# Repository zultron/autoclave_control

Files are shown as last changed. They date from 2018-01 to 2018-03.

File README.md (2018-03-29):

# Machinekit Autoclave control

This project is the design for an autoclave control using Machinekit
and a BeagleBone.  It controls a heat element and a pressure relief
valve using thermistors for input.

This repo is a rework of the [Goldibox][goldibox] project repo.

[goldibox]: https://github.com/zultron/goldibox/

## Components

The autoclave controller is a BeagleBone computer running Debian.  It
senses temperatures through a pair of thermistors attachd to its
analog inputs, and it switches the heat element and pressure relief
valve through two solid-state relays (SSRs) connected through GPIO
digital output pins.  See `electronics/autoclave.fzz` for connecting
them.

The [Machinekit][machinekit] software runs the configuration in this
repository:  some python user-space components in the `bin/`
directory, and HAL configuration in the `hal/` directory.  The
`autoclave-control` component decides whether to switch the relief
valve and burner on or off, depending on the program cycle and the
measured temperature.  The `autoclave-logger` component logs to a RRD
database, from which time series charts are generated.

The `autoclave-control` component exposes a remote UI, used by the
`MachinekitClient` software, which can be downloaded for Android from
the Google Play store, and for Linux, Mac OS X and Windows directly
from the [QtQuickVCP][qqvcp] project.  See the below screenshot.  The
idle, boil, steam and heat stages in green are done.  The current
stage is 15+ minutes into a 30 minute sterilization.  That and the
blue-colored cool stage are not yet done.  The button controls on the
left are enable/disable, start/stop, and a link to the graphs.  The
indicators on the upper right are process elapsed time, burner duty
cycle, pressure and temperature.

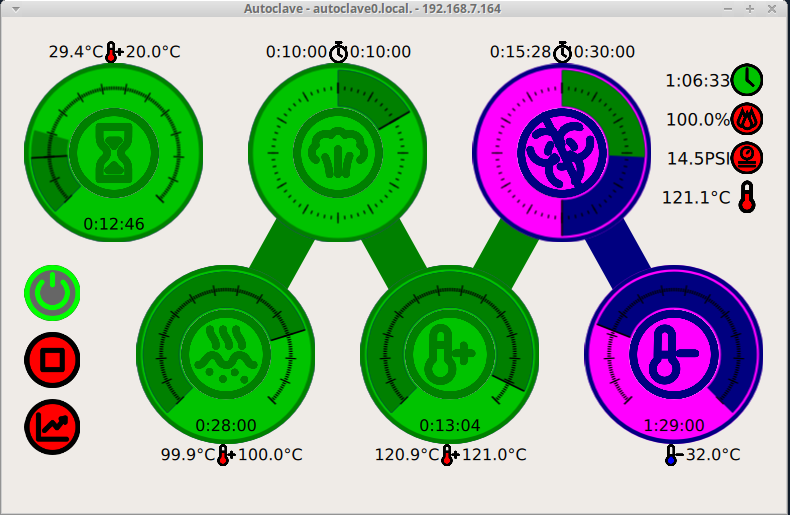
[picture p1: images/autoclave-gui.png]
Autoclave GUI


The `autoclave-logger` component captures process data with
[rrdtool][rrdtool] and generates graphs like the one below, which
shows an entire cycle on a real machine.  The autoclave was already
warmed up to 29.4 deg. from a previous run when the start button was
pressed shortly after 03:00.  The water was heated to 100 degrees in
the boil stage, and the valve was opened (thick blue curve) for ten
minutes with the burner at 100% (yellow curve; 0% at 100, 100% at
110).  Then the valve closed and the autoclave was heated to the 121
degree sterilization temperature.  Pressure was also measured at 15
PSIG (solid orange curve).  After 30 minutes, the burner was turned
off and the autoclave cooled to 32 degrees (not shown), and the cycle
was finished.  After that, the autoclave switch back to idle mode at
20 degrees.

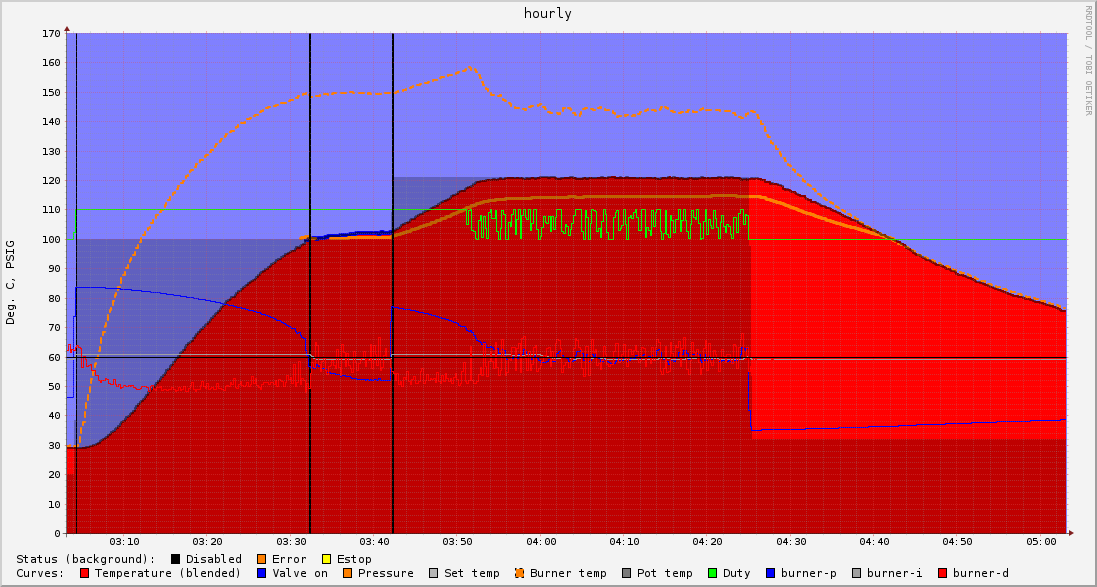
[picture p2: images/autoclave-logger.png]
Autoclave logger


[rrdtool]: https://oss.oetiker.ch/rrdtool/

FIXME:  configuration?

# Running

Follow the instructions at [machinekit.io][machinekit] to download and
install a mini-SD card image with Machinekit.  Log into the BeagleBone.

On the BeagleBone, install the `python-yaml` package.

     sudo apt-get install -y python-yaml

Clone this repository, and `cd` into the repository directory.

     git clone https://github.com/zultron/autoclave_control
     cd autoclave_control

On the BeagleBone, start the Autoclave control from the command line
(load the overlay file for non-system installs):

    # Install minimal apache and other config
    sudo make install MININSTALL=1
    # Start control
    bin/autoclave -o

The Autoclave should now be ready for control.  Start the
[MachinekitClient][qqvcp] and open the Autoclave app.

Alternatively, run an Autoclave simulated control and GUI in a Docker
container from the command line:

    # Start the container
    docker/qqvcp.sh
    # Install minimal apache and other config
    sudo make install MININSTALL=1
    # Start control
    bin/autoclave &
    # Start GUI
    MachinekitClient &

The Autoclave may be installed to the system so that it is run at
every boot:

    sudo make install
    sudo systemctl daemon-reload
    sudo systemctl enable autoclave
    sudo systemctl start autoclave

The `apache2` package must be installed and the web server running for
the time-series chart to work.

# Installing the BeagleBone

FIXME

[wiki-peltier]: https://en.wikipedia.org/wiki/Thermoelectric_cooling
[machinekit]: http://www.machinekit.io/
[qqvcp]: https://github.com/qtquickvcp/QtQuickVcp

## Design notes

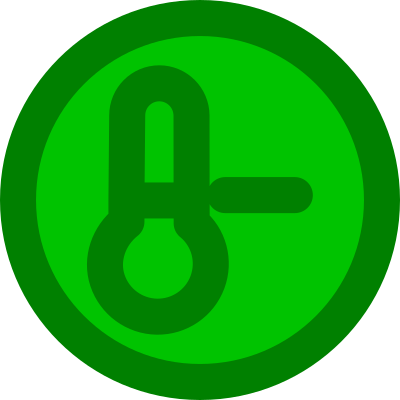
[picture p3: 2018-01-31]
qml/autoclave-remote/Autoclave/assets/p5-cool-green.png

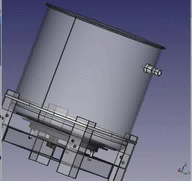
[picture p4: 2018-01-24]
autoclave.gif

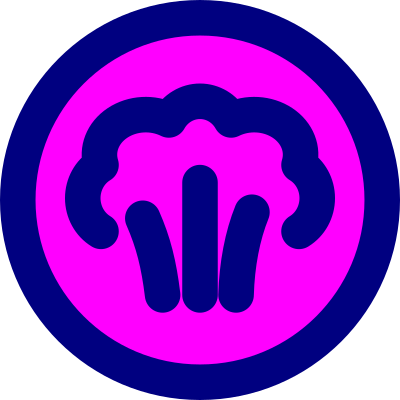
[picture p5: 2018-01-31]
qml/autoclave-remote/Autoclave/assets/p2-flush-blue.png

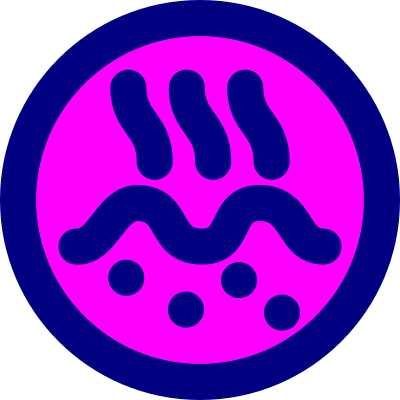
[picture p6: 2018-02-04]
qml/autoclave-remote/Autoclave/assets/p1-boil-blue.png

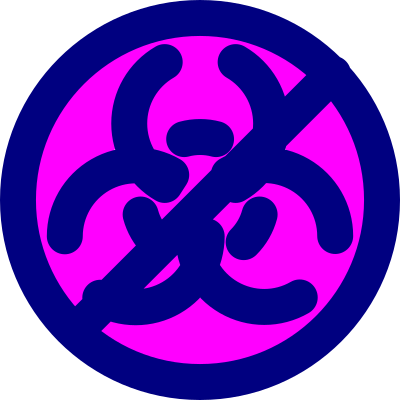
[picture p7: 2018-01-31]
qml/autoclave-remote/Autoclave/assets/p4-sterilize-blue.png

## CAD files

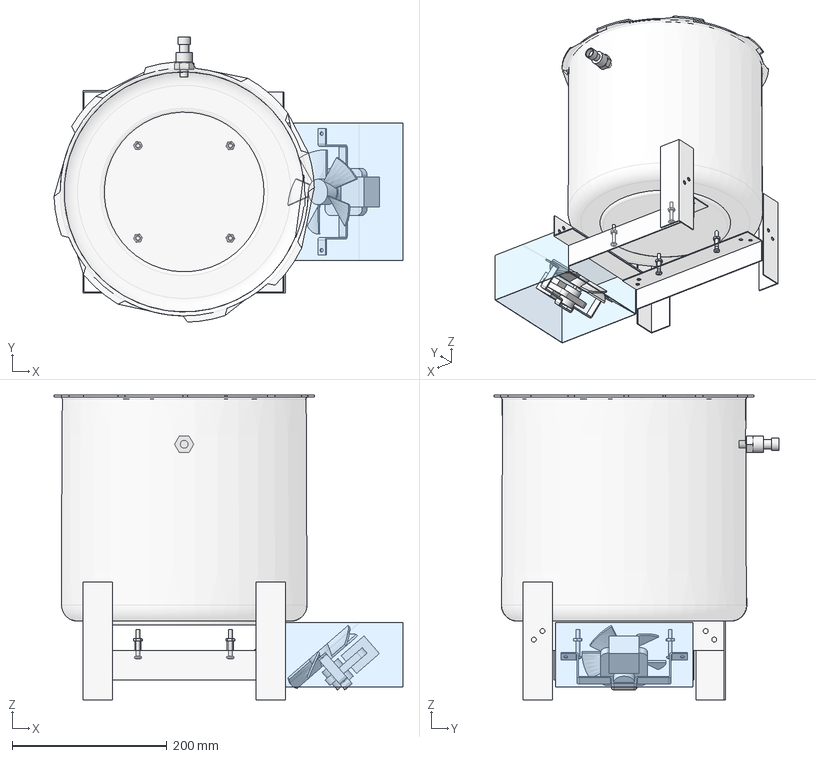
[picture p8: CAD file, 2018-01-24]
hardware/autoclave.fcstd
450.9 x 368.6 x 393.7 mm
pot-support-2
pot
burner-support-v2-1
burner-support-v2-2
leg1
leg2
leg3
spring1
spring2
spring3
spring4
burner-unk-nut1
burner-unk-nut2
burner-unk-nut3
burner-unk-nut4
pressure-sensor
burner-10X1.25-screw1
burner-10X1.25-screw2
burner-10X1.25-screw3
burner-10X1.25-screw4
fan
fan-shroud

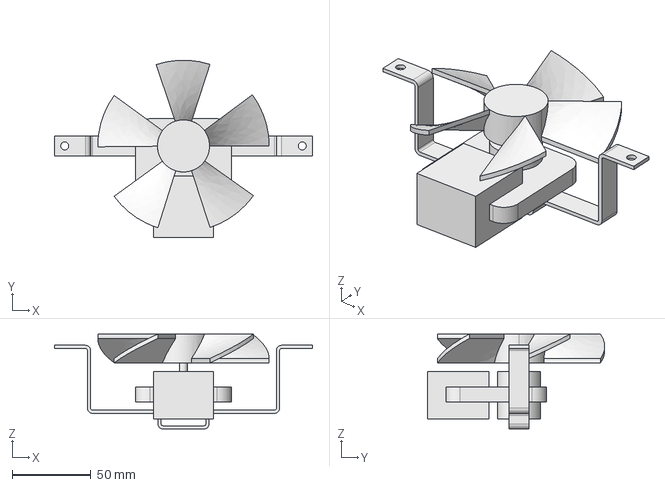
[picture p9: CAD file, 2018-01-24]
hardware/fan.fcstd
163.6 x 112.4 x 60.2 mm

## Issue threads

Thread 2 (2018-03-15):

GUI:  Add panel for 'advanced' settings

zultron, 2018-03-15:
- Pot, burner and pressure gain and bias
- Others?

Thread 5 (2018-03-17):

Above 100 deg., switch PID input to pressure sensor

zultron, 2018-03-17:
The pressure sensor input is more stable and more instantaneous, and would be better as the PID feedback.

- PID params will likely need to be changed; could swap out whole PID?
- Temp and pressure sensors need to be in sync for hand-off
- In my design, where the pressure sensor is connected with a hose, water collects and puts a 0.3-0.4 PSI bias on the sensor
- These sensors can be unreliable, so be sure temp sensors are hooked up to safety mechanisms

Closed 2018-03-23.

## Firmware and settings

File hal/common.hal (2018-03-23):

# ################################################
# E-Stop and error LUT
# ################################################
#
# The E-stop is serious:  it not only disables the burner, but also
# opens the relief valve
#
# Error is less serious:  it disables the burner and relief valve
#
# Enable is least serious, and acts like error

# lut5 docs
# http://linuxcnc.org/docs/devel/html/man/man9/lut5.9.html

# - Load comp
newinst lut5 valve
addf valve                          main-thread
newinst lut5 enable
addf enable                         main-thread

# - Configuration
#
# in-3	in-2	in-1	in-0	| out		| out
# estop	error	en-sw	input	| valve		| enable
# ----- ------	------	------	| ------	| ------
# 0	0	0	0	|		|
# 0	0	0	1	|		|
# 0	0	1	0	|		| 0x0004 # in-0 not
# 0	0	1	1	| 0x0008	| 0x0008 # connected
# 0	1	0	0	|		|
# 0	1	0	1	|		|
# 0	1	1	0	|		|
# 0	1	1	1	|		|
# 1	0	0	0	| 0x0100	|
# 1	0	0	1	| 0x0200	|
# 1	0	1	0	| 0x0400	|
# 1	0	1	1	| 0x0800	|
# 1	1	0	0	| 0x1000	|
# 1	1	0	1	| 0x2000	|
# 1	1	1	0	| 0x4000	|
# 1	1	1	1	| 0x8000	|
#				| ------	| ------
setp valve.function		  0xff08
setp enable.function				  0x000c

# Valve LUT
# - Inputs
net estop                           => valve.in-3
net error                           => valve.in-2
net enable-switch                   => valve.in-1
net valve-on-input                  => valve.in-0
# - Output
net valve-on                        <= valve.out

# Enable LUT
# - Inputs
net estop                           => enable.in-3
net error                           => enable.in-2
net enable-switch                   => enable.in-1
# - Output
net enable                          <= enable.out



# ################################################
# Autoclave control comp
# ################################################

# Load userland comp
loadusr -W autoclave-control

# Remote controls
# - Enable-switch, True/False
net enable-switch                   => autoclave-control.enable-switch
# - Start/stop, True/False
net start                           => autoclave-control.start

# Process stage settings and status
# - Current stage, ID
net stage                           <= autoclave-control.stage
# - Idle stage:  heat
net idle-temp-set                   => autoclave-control.idle-temp-set
net idle-temp                       <= autoclave-control.idle-temp
net idle-time                       <= autoclave-control.idle-time
# - Boil stage:  heat
net boil-temp-set                   => autoclave-control.boil-temp-set
net boil-temp                       <= autoclave-control.boil-temp
net boil-time                       <= autoclave-control.boil-time
# - Flush stage:  timer
net flush-time-set                  => autoclave-control.flush-time-set
net flush-time                      <= autoclave-control.flush-time
# - Heat stage:  heat
net heat-temp-set                   => autoclave-control.heat-temp-set
net heat-temp                       <= autoclave-control.heat-temp
net heat-time                       <= autoclave-control.heat-time
# - Sterilize stage:  timer
net ster-time-set                   => autoclave-control.ster-time-set
net ster-time                       <= autoclave-control.ster-time
# - Cool stage:  cool
net cool-temp-set                   => autoclave-control.cool-temp-set
net cool-temp                       <= autoclave-control.cool-temp
net cool-time                       <= autoclave-control.cool-time

# Controls out
# - Burner temp
net temp-set                        <= autoclave-control.temp-set
# - Burner output override (added to PID output)
net burner-override                 <= autoclave-control.burner-override
# - Pressure relief valve
net valve-on-input                  <= autoclave-control.valve-on

# Sensors in/limits out
# - Pressure
net pressure                        => autoclave-control.pressure
net pressure-bias                   <= autoclave-control.pressure-bias
net pressure-gain                   <= autoclave-control.pressure-gain
net pressure-max                    <= autoclave-control.pressure-max
# - Pot temperature, deg. C
net temperature                     => autoclave-control.temperature
# - Pot thermistor
net temp-pot-therm                  => autoclave-control.temp-pot
net temp-pot-bias                   <= autoclave-control.temp-pot-bias
net temp-pot-gain                   <= autoclave-control.temp-pot-gain
net temp-pot-max                    <= autoclave-control.temp-pot-max
# - Burner thermistor
net temp-burner-therm               => autoclave-control.temp-burner
net temp-burner-bias                <= autoclave-control.temp-burner-bias
net temp-burner-gain                <= autoclave-control.temp-burner-gain
net temp-burner-max                 <= autoclave-control.temp-burner-max

# Other status
# - Overall elapsed time, s.
net time-elapsed                    <= autoclave-control.time-elapsed
# - Enable, True/False
net enable                          => autoclave-control.enable
# - Error, True/False
net error                           <= autoclave-control.error
# - E-Stop, True/False
net estop                           => autoclave-control.estop
# - Shut down
net shutdown                        => autoclave-control.shutdown


# ################################################
# Temp signal filters
# ################################################

# Lowpass filter comps:  filter out <2s. lambda noise (main-thread 10 Hz)
# https://www.embeddedrelated.com/showarticle/779.php
# delta_t = 0.1; tau = 2; gain = alpha = 0.1/2 = 0.05
# This causes a small lag in exchange for steadier signals.
#
# - Pot
newinst lowpass temp-pot
net temp-pot-therm                  => temp-pot.in
net temp-pot                        <= temp-pot.out
net load                            => temp-pot.load
setp temp-pot.gain                  0.05
addf temp-pot                       main-thread
#
# - Burner
newinst lowpass temp-burner
net temp-burner-therm               => temp-burner.in
net temp-burner                     <= temp-burner.out
net load                            => temp-burner.load
setp temp-burner.gain               0.05
addf temp-burner                    main-thread

# ################################################
# Pressure to temp conversion
# ################################################

# Boiling point of water at 1 atm. (14.7 PSIA) is about 100 deg.;
# at 14.7 + 15.0 PSIA (at sea level) is 121 deg;
# use 21.0 deg. / 15.0 PSIG = 1.4 deg./PSI as conversion factor, so:
# deg = PSIG * 1.4 deg/PSIG + 100 deg

newinst sum2 press-to-temp
net pressure                        => press-to-temp.in0
setp press-to-temp.gain0            1.4
setp press-to-temp.in1              100
net temp-pressure                   <= press-to-temp.out
addf press-to-temp                  main-thread

# ################################################
# Temp switch
# ################################################

# The pressure sensor is much more stable than the thermistors, but
# can only be used above 100 deg.  The following makes it possible to
# use a blended temperature signal from the thermistor and pressure
# sensors.  It is disabled here.

# Base signal on:
# - temp-pot below 5 PSI
# - temp-pressure above 10 PSI
# - fade from temp-pot to temp-pressure between 5 and 10 PSI

# The select signal:  convert the 5-10 PSI range into 0.0-1.0 with
# pressure/5.0 - 1.0 (values outside that range are clipped)
newinst sum2 temp-blend-select
net pressure                        => temp-blend-select.in0
setp temp-blend-select.gain0        0.2
setp temp-blend-select.in1          -1.0
net temp-blend-select               <= temp-blend-select.out
addf temp-blend-select              main-thread

# The blended signal:  1.0 for pressure, 0.0 for thermistor
newinst blend temp-blend
net temp-pressure                   => temp-blend.in1
net temp-pot                        => temp-blend.in2
net temp-blend-select               => temp-blend.select
net temperature                     <= temp-blend.out
setp temp-blend.open                0
addf temp-blend                     main-thread

# Disable blending and use only thermistor for temperature.
unlinkp temp-blend-select.out
sets temp-blend-select              0.0

# ################################################
# Burner PID input signals
# ################################################

# Add feedback derivative w/low-pass
#
# MK PID comp seems to have dropped internal derivative code

# - Derivative
newinst ddt temp-ddt
net temperature                     => temp-ddt.in
net temp-ddt-raw                    <= temp-ddt.out
addf temp-ddt                       main-thread

# - Low-pass filter
# (See above for calculations)
newinst lowpass temp-ddt-filter
net temp-ddt-raw                    => temp-ddt-filter.in
net temp-ddt                        <= temp-ddt-filter.out
net load                            => temp-ddt-filter.load
setp temp-ddt-filter.gain           0.01
addf temp-ddt-filter                main-thread
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

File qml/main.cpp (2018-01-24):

/****************************************************************************
**
** Copyright (C) 2014 Alexander Rössler
** License: LGPL version 2.1
**
** This file is part of QtQuickVcp.
**
** All rights reserved. This program and the accompanying materials
** are made available under the terms of the GNU Lesser General Public License
** (LGPL) version 2.1 which accompanies this distribution, and is available at
** http://www.gnu.org/licenses/lgpl-2.1.html
**
** This library is distributed in the hope that it will be useful,
** but WITHOUT ANY WARRANTY; without even the implied warranty of
** MERCHANTABILITY or FITNESS FOR A PARTICULAR PURPOSE. See the GNU
** Lesser General Public License for more details.
**
** Contributors:
** Alexander Rössler @ The Cool Tool GmbH <mail DOT aroessler AT gmail DOT com>
**
****************************************************************************/
#include <QApplication>
#include <QQmlApplicationEngine>

int main(int argc, char *argv[])
{
    QApplication app(argc, argv);

    QQmlApplicationEngine engine;
    engine.addImportPath(QStringLiteral("imports"));
    engine.addImportPath(QStringLiteral("assets:/imports"));
    engine.load(QUrl(QStringLiteral("qrc:///main.qml")));

    return app.exec();
}

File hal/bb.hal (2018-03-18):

#!/usr/bin/env halrun
# ################################################
#
# Autoclave BeagleBone HAL configuration
#
# http://linuxcnc.org/docs/devel/html/man/man1/halcmd.1.html
#
# ################################################
# Load and plumb comps
# ################################################

# ################
# Thermistor
# - 100k thermistors with 1k pull-up resistor:  burner on AIN1, pot on
#   AIN3; 40 samples in low-pass filter (20 second window)
#     https://github.com/machinekit/machinekit/blob/master/src/hal/user_comps/hal_temp_bbb.py

# - Load thermistor comp
loadusr -Wn therm hal_temp_bbb -n therm -c 01:epcos_B57560G1104,03:epcos_B57560G1104 -b CRAMPS -r 1000 -f 40
# - Burner temp signal
net temp-burner-therm               <= therm.ch-01.value
net temp-burner-bias                => therm.ch-01.bias
net temp-burner-gain                => therm.ch-01.gain
# - Pot temp signal
net temp-pot-therm                  <= therm.ch-03.value
net temp-pot-bias                   => therm.ch-03.bias
net temp-pot-gain                   => therm.ch-03.gain

# ################
# Pressure sensor
# - 5V pressure sensor on AIN5
loadusr -W hal_press_bbb -c 05
net pressure                        <= hal_press_bbb.ch-05.value
net pressure-bias                   => hal_press_bbb.ch-05.bias
net pressure-gain                   => hal_press_bbb.ch-05.gain

# ################
# Threads

# - One slow thread, 10 Hz
loadrt threads name1=main-thread period1=100000000

# ################
# BeagleBone GPIOs
#     http://linuxcnc.org/docs/devel/html/man/man9/hal_bb_gpio.9.html
# - pinouts
#     http://beagleboard.org/support/bone101
# - Pressure relief valve SSR on P9.18
# - Burner SSR on P9.22

loadrt hal_bb_gpio board=BeagleBone output_pins=918,922 input_pins=942
addf bb_gpio.read                   main-thread
addf bb_gpio.write                  main-thread

# - Burner SSR on/off
net burner-on                       => bb_gpio.p9.out-22

# - Pressure relief SSR on/off
net valve-on                        => bb_gpio.p9.out-18

# - E-stop
net estop                           <= bb_gpio.p9.in-42

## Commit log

2018-01-24 Initial commit of goldibox files
    from https://github.com/zultron/goldibox, rev 5721c02f
    [common.hal, goldibox.fzz, pb.hal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]
2018-01-24 Superficially rename goldibox to autoclave
    [common.hal, goldibox.fzz, pb.hal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]
2018-01-24 electronics/autoclave.fzz: change burner GPIO pin
    ...to P9.22 for BB white compatibility
    [autoclave.fzz]
2018-01-24 Move hal/pb.hal to hal/bb.hal
    [bb.hal]
2018-01-25 First try at HAL rework
    Totally untested; logger needs help; GUI needs more
    [bb.hal, common.hal, sim.hal]
2018-01-25 Add E-stop to Fritzing
    [autoclave.fzz]
2018-01-25 Update spreadsheet sim
    [sim-model.ods]
2018-01-25 Plumb estop into BB HAL
    [bb.hal]
2018-01-25 Fix HAL problems preventing startup
    [common.hal]
2018-01-31 qml: add icons; add pin bindings; first mock-up with dials
2018-02-02 Control comp and GUI refactor
    Control comp & related HAL config & comps refactoring:
    - Separate setting, feedback and time pins for each process stage
    - Introduce control comp `pin_data[]` structure
    - Clean up control comp `enter_stage()` and other functions
    GUI:
    - Add time and temp text read-out widgets, plus HAL-connected versions
    - Clean up time and temp stage dial widgets and add time readout
    - Update Pins
    Other fixes:
    - Fix settings persistence
    - Don't exit on control comp error
    - Catch exit signal in control comp
    FIXME:
    - Logger comp temporarily disabled
    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
    [common.hal]
2018-02-02 Fix *-set pin bindings and remove test code
2018-02-03 autoclave-control: print traceback on exceptions
2018-02-03 common.hal: fix enable inputs
    [common.hal]
2018-02-03 Add CheckButton qml type and enable & start buttons
2018-02-03 HALTimeReadout: assume pin direction always in
2018-02-04 autoclave-control:
    - Fix stage and elapsed timers
    - Fix enable signal plumbing
2018-02-04 Fix sim model
    Tweaks to make spreadsheet and sim comp agree
    [sim-model.ods]
2018-02-04 Lots of changes; system nearly working
    - Add extra "boil" stage to get to 100 deg. for flush cycle
    - New icons & configuration
    - Fix more issues with GUI not updating after autoclave restart
    - Teach sim comp how to simulate open valve
    - Hook up sim comp pressure signal
    - Do initial PID tuning
    - Fix bugs from "sterilize" stage name not matching "ster-*" pin names
    - Fix bugs computing if stage time has elapsed
    - Fix bugs with stages needing max heat
    - Fix bugs progressing between stages
    - Info messages
    - Notify when valve opens/closes
    - Notify regularly enable signal status
    - Parameterize notification interval & rationalize time mgmt in sim comp
    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
    [common.hal, sim.hal]
2018-02-04 bin/autoclave: Report launcher errors
    stopping configserver... Traceback (most recent call last):
    File "bin/autoclave", line 158, in <module>
    launcher.end_session()
    File "/usr/lib/python2.7/dist-packages/machinekit/launcher.py", line 15, in end_session
    stop_processes()
    File "/usr/lib/python2.7/dist-packages/machinekit/launcher.py", line 102, in stop_processes
    os.killpg(process.pid, signal.SIGTERM)
    OSError: [Errno 3] No such process
2018-02-04 Explicitly load common.hal from bin/autoclave
    [bb.hal, sim.hal]
2018-02-04 Put sim temp-ext setting in saved state file
    [sim.hal]
2018-02-04 Tune leakage_factor and PID settings
    [common.hal]
2018-02-05 UI tweaks
    - Stages now use states
    - Default state is blue setting state, no read value shown
    - Progress state is when stage in progress; read readout and arc shown
    - Done state is when stage finished; everything turns green
    - Changes happen with smooth transitions
    - Fix time setting update, again
    - Why the binding loop?
    - Zero handles disabled
    - Start icon checked looks like stop button
2018-02-05 Implement cool-down control
    - DialGauge can now have minPos > maxPos and minValue > maxValue
    - set and read arcs still start from minPos, but are drawn counter-clockwise
    - minor/majorGrad properties must be negative in this case
    - Set up in GUI cool-down stage
2018-02-06 Enable mouse wheel adjustments
2018-02-06 Add background with progression links between stages
2018-02-06 autoclave-control: step set_sense_delta back up to 1.0
    Workaround for not having cool stages force burner to zero
2018-02-06 Move Pins.stage to Background object
2018-02-06 autoclave control: 'cool' stage is now a zero burner stage
2018-02-06 sim-model.ods: commit unknown changes
    [sim-model.ods]
2018-02-06 Logger now working
    [common.hal]
2018-02-06 logger: fix valve; tweak graphs
2018-02-06 Make saving status more reliable & efficient
    - From control, check every minute if state has changed & update if so
    - Only control saves status; eliminate race conditions
    - Plumb `temp-ext` pin into control for sim comp
    - Write state to temp file and rename to state file to avoid corruption
    after interrupt
    - Save `enable-switch` state, not `enable` state
    - Tweak output messages: less verbose but more informative
    [common.hal]
2018-02-06 autoclave sim-temp: don't add randomness
    The hal_temp_bbb comp implements a low-pass filter, so no need to
    simulate something that's not there. Also, this is breaking attempts
    to use the PID's D input.
2018-02-06 hal: tune PID for sim
    - Slow down main thread to match userland comp update times
    - This allows calculating the derivative of the feedback
    - Add ddt comp to calculate fb derivative
    - The MK PID comp doesn't generate fb-deriv anymore
    - Tune PID parameters
    [bb.hal, common.hal, sim.hal]
2018-02-07 logger: tweak graphs
    stage ticks; legend comments
2018-02-07 Improve burner efficiency between stages
    The burner was trying to grease up to 100 deg. in the boiling stage,
    but there's no reason not to blast into it. Also, for the flush
    stage, the charts look funny with an artificial set temp.
    Related, the burner was trying to grease down to 99 deg. in the cool
    stage, but there's no reason not to drop past that into idle.
    Fix this by adding in a separate `burner-override` signal the control
    can set to clobber the effect of the PID comp before it goes into the
    limiter.
    [common.hal]
2018-02-07 hal: final PID tuning for sim
    Overshoots 0.015 deg. at max, and reduced burner at <0.3 deg. error
    [common.hal]
2018-02-07 Remove all the `temp-ext` apparatus
    Just hard-code it in the sim comp in a variable
    [common.hal, sim.hal]
2018-02-07 Leave enable-switch off after start-up
    For safety's sake
2018-02-07 GUI: remove obsolete label showing stage
2018-02-07 Add chart button
    - New icon
    - New ChartsButton widget replaces old TimeSeries
    - This is just a button, not a mini-graph itself
    - Move things around in GUI to squeeze it in
2018-02-24 Change valve SSR pin
    from 22 to 20; seems this was done in Fritzing already
    [bb.hal]
2018-02-26 Revert "Change valve SSR pin"
    This reverts commit d02195e0ccb17fc3cb3325c8fe2560c306747096.
    The mistake is in the Fritzing, not in the pin configuration
    [bb.hal]
2018-02-26 Swap burner and valve GPIOs in Fritzing
    Match HAL and config-pin configurations
    [autoclave.fzz]
2018-02-26 Add transistors to SSR signals
    The BB GPIO output is 6mA, but the SSR input needs 7.5mA.
    [autoclave.fzz]
2018-02-26 Clean up Fritzing
    [autoclave.fzz]
2018-03-11 Swap burner and valve pins
    This has been done already in fritzing
    [bb.hal]
2018-03-11 autoclave.fzz: Another big fat cleanup
    Clean up a lot of wire folding errors
    [autoclave.fzz]
2018-03-11 Add hal_press_bbb comp and load in HAL config
    This comp is based on the hal_temp_bbb comp.
    [bb.hal]
2018-03-11 hal/bb.hal: switch to 100k thermistors
    Thermistor config originally copied from Goldibox, which uses 10k thermistors
    [bb.hal]
2018-03-12 Add gain and bias pins to temp and pressure comps
    [bb.hal]
2018-03-15 bin/autoclave: Print exception when crashing
2018-03-15 Add low-pass filter to temp inputs
    Lots of noise esp. at lower temps, and we want more stable inputs for
    PID controller.
    Do this with a low-pass filter, filtering signals greater than 0.1 Hz.
    This leads to a 0.5 deg. error when heating in simuation.
    In sim, re-add randomness from commit e5032824.
    The HAL low-pass filter is the one-liner discussed here.
    https://www.embeddedrelated.com/showarticle/779.php
    [bb.hal, common.hal, sim.hal]
2018-03-16 autoclave-sim-temp: tune model to mimic real life
    These number get the sim model pretty close to my real life version.
    See the spreadsheet.
    The transfer rate had to be fudged, revealing how the code should be
    simplified. See issue #4.
    [sim-model.ods]
2018-03-16 common.hal: add `load` signal for low-pass filters
    [common.hal]
2018-03-16 common.hal: add low-pass filter to burner command
    The low-pass filters on the temp sensors help a lot, and make the GUI
    output a lot prettier. However, the burner duty cycle jumps all over
    the place, and begs to be smoothed out.
    [common.hal]
2018-03-16 common.hal: update PID params for new model
    These actually overshoot quite a lot, probably more with the burner
    output low-pass filter, but I want to tune them on the real thing, so
    committing early.
    [common.hal]
2018-03-17 common.hal: Add low-pass filter to PID ddt input
    This seems to smooth everything out.
    [common.hal]
2018-03-17 common.hal: PID param tweaks
    These tweaks pretty much take care of overshoot. The large I
    component was wiping out the D component when approaching w/in a
    couple of degrees, and would turn on the burner partway, leading to an
    unclean curve.
    At 120 deg. set, oscillation btw. 119.7 and 119.9. The I param may
    need to be increased slightly.
    [common.hal]
2018-03-17 common.hal: tweak temp in low-pass filters
    Try to stabilize temp readings.
    [common.hal]
2018-03-17 common.hal: increase burner-duty low-pass filter gain
    Stop 5-minute period oscillations
    [common.hal]
2018-03-17 common.hal: Tweak Igain
    Stable level about 0.3 deg. low
    [common.hal]
2018-03-18 common.hal: Tweak temp low-pass filter gain
    Gain was way too low, causing about 5 deg. diff.
    [common.hal]
2018-03-18 common.hal: put PID ddt comp on raw temp signal & adjust filter
    Too many filters in a row cause lag.
    Decrease ddt filter gain, since temp accel is very low.
    [common.hal]
2018-03-18 common.hal: redo PID tuning
    Old params were too loose; undershoot that couldn't be corrected
    [common.hal]
2018-03-18 common.hal: tweak PID I & D to stop 0.2 deg. overshoot
    [common.hal]
2018-03-18 Plumb pressure and pot/burner temps to control and save state
    These are important settings on a real sterilizer. On the sim
    sterilizer, they don't actually do anything.
    This is a prerequisite for issue #2, exposing these settings via GUI.
    [bb.hal, common.hal]
2018-03-18 Create composite temp signal from thermistor and pressure sensors
    The thermistor input is unstable, and at high temps, where we want
    good control, it wanders around causing fluctuations of 0.5 deg. or
    more. This might be fixed with PID settings or something, but the
    nice, stable pressure signal makes a good replacement.
    Since the pressure signal is only meaningful above 100 deg., use the
    thermistor under 105, the pressure signal above 110, and blend them
    while in between.
    Fixes #5
    [bb.hal, common.hal, sim.hal]
2018-03-18 common.hal: pull in PID and filter settings from real machine
    [common.hal]
2018-03-19 common.hal: disable lowpass filters; PID param tweaks for real machine
    [common.hal]
2018-03-19 common.hal: reorg burner output chain & fix plumbing
    See previous commit
    [common.hal]
2018-03-19 Add PID curves to graphs for tuning
    [common.hal]
2018-03-19 common.hal: re-add ddt low-pass filter & increase gain
    [common.hal]
2018-03-20 common.hal: reorg PID input section for clarity
    [common.hal]
2018-03-20 Add double derivative & gain as new term for PID control
    [common.hal]
2018-03-20 common.hal: Show auto-tune config & paramers
    This was a failure, however.
    [common.hal]
2018-03-20 common.hal: fix 1st and 2nd derivative filters
    [common.hal]
2018-03-22 autoclave-logger: fix horizontal rule for PID center
2018-03-22 bin/hal_*_bbb: don't round output values
    Messes with PID derivatives
2018-03-22 common.hal: tune real machine
    These settings are fairly stable, but undershoot and can take a while
    to get up to temp and stabilize.
    The integral product pretty much settles at 0.5 at 121 deg. It also
    causes some instability and is slow to adjust itself (since the burner
    is usually saturated until things stabilize) so I'm debating zeroing
    this out and trying again at setting a burner.bias that varies
    proportionally to the difference with ambient temp.
    [common.hal]
2018-03-22 common.hal: increase D input low-pass filter gain
    This seemed to cause a ~4 minute period oscillation and +/-0.3 deg. errors.
    [common.hal]
2018-03-23 Revert "Add double derivative & gain as new term for PID control"
    This reverts commit e0fb1046265da82aebef54d59ebd2eaaae194fb3.
    The double derivative stuff wasn't helpful in the end. The
    oscillation problem it meant to solve was fixed by increasing low-pass
    filter gains and by not rounding sensor inputs in the `bin/hal_*_bbb`
    comps.
    [common.hal]
2018-03-23 common.hal: more real machine tweaks
    Set a 0.5 burner bias so that things are close to zeroed out at 121
    deg. That takes the place of a portion of the I band, so the max I
    can be reduced. Finally, remove the `maxoutput` restriction so that
    the I band will continue to adjust even when the burner is saturated.
    [common.hal]
2018-03-23 common.hal: clean up comment cruft
    [common.hal]
2018-03-23 common.hal: put burner limit after override
    Burner readout read 300% with override on, e.g. during boil phase
    where burner is forced on
    [common.hal]
2018-03-23 autoclave-control: fix burner override
    Limits were removed from PID `maxoutput`; set burner override to
    ridiculously high value to overcome this
2018-03-23 common.hal: add burner bias signal to PID
    Compensate for heat loss with a bias that increases proportionally to
    the difference of ambient temperature. Assume 60% at 120 deg. and
    ambient temp is 20 deg.
    [common.hal]
2018-03-23 common.hal: disable blended temp signal and use only thermistor
    With previous tuning, the thermistor now works OK for the temperature
    signal. The pressure signal is good, except the way I have mine
    connected, its tube can fill with water and change the signal by 0.5
    PSI.
    [common.hal]
2018-03-23 common.hal: fixup fa14357f "add burner bias signal to PID"
    60% factor left out
    [common.hal]
